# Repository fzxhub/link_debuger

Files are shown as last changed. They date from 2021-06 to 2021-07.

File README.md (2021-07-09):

# link_debuger_stm32
Includes STLINK JLINK DAPLINK, used for microcontroller debugging.
## 简介
本项目是一个link debuger，用于调试带有JTAG、SWD接口的微控制器。由于SWD接口的优势，以及本项目宗旨是做一个美观、小巧、功能全的调试器，因此查阅了许多开源电路、开源固件。最终做了该PCB。由上下两层PCB通过铜柱连接在一起。铜柱复用为上下板供电线路。
#### 优点
- 小巧、多功能
- 插针隐藏设计、方便携带
- 支持Jlink、STlink、DAPlink
- 支持RS485调试
- 支持ESP32等IC的自动下载（RTS、DTR信号预留）
- 使用Typec接口的对称性改成SWD、UART信号接口
- 采用底板顶板贴合设计、铜柱复用电源连接底板顶板
#### 实物展示
avatar

avatar

avatar

#### **底板3D图**
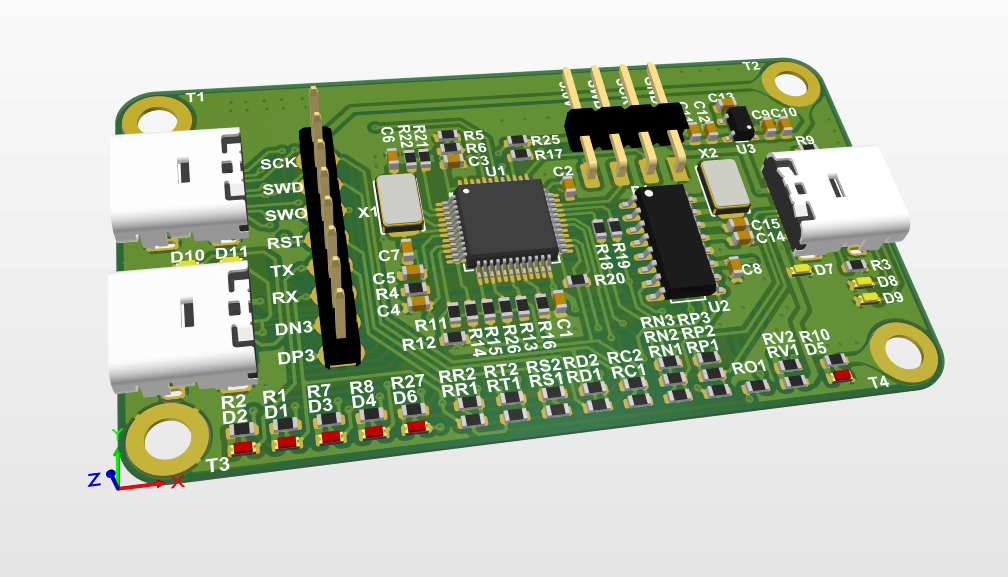
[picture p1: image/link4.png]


## 功能
1. debuger（jlink、stlink、daplink任意中的一种）
	- SWD接口下载和调试功能
	- link虚拟的串口功能（需要jlink、stlink、daplink固件支持）
	- link支持拖拽下载（需要jlink、stlink、daplink固件支持）
2. USB转UART（CP2102虚拟的串口）
3. USB转RS485（RS485由CP2102的UART电平转化，同一时刻只使用一种，EN接通使用RS485，不接使用UART）
4. USB HUB（可以再接入其他1个USB设备，TYPEC接口）
5. 信号线交叉硬件设计
## 功能说明
- link功能表示可是使用jlink、stlink、daplink任意一种固件，烧录入不同的link固件，该设备就是可以实现变身。
- USB转串口功能，因为三种固件都支持虚拟UART功能，因此都可以使用USB转UART（TTL），下载、调试、UART调试集一身。
- 除了固件虚拟的UART，再接入一个CP2102虚拟一个串口，该串口主要引出RTS、DTR信号，在目标板上合理设计可以自动下载ESP32、STM32串口下载。
- 还将CP2102虚拟的UART（TTL）进行电平转换后得到RS485接口，用于RS485调试
- 在输入USB接口之后绘制了一个USB HUB芯片，芯片是支持一拖四USB HUB，速率达到USB2.0。可通过电阻选择USB HUB是否使用。设计成可选择，主要防止USB HUB的不稳定造成link debugger的不稳定，如USB HUB不稳定或者不使用，可进行硬件上的切换。切换方式通过丝印在背面。
- 信号线交叉设计主要用于在电路设计时大意将例如UART的RX、TX接错时可切换debuger的电阻即可。切换方式通过丝印在背面。
- 本设计接口使用了typec USB接口定义了SWD接口、UART接口。在设计你的原型电路时，可以使用typec USB来设计SWD、UART接口后，通过typec USB线连接PC、link debuger、原型电路即可开始下载与调试。
- 该设备输出共四个typec USB：
  - typec USB1：SWD、UART接口
  - typec USB2：固件虚拟的UART接口 
  - typec USB3：CP2102虚拟的UART接口，带DTR、RTS信号
  - typec USB4：USB HUB接口
### **接口定义**
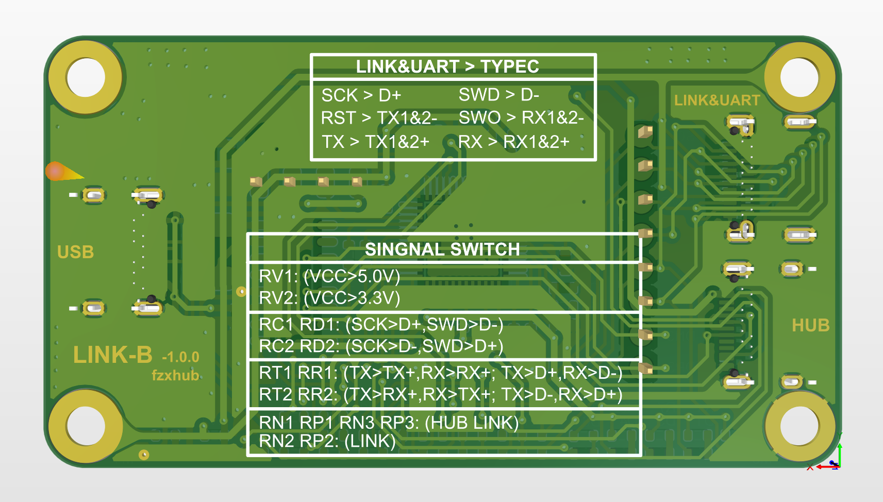
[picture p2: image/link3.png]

## 支持固件类型
1. jlink
2. stlink
3. daplink
## 支持接口与定义
说明：个人觉得嵌入式开发调试接口20PIN的牛角座端子太大，不适合在开发板或者项目电路板上使用，直接使用插针的方式在电路板使用，当迁移电路板后需要再次每根杜邦线连接，累~，在USB接口定义有可以直接使用的线和接口，因此我想使用USB线来做我们SWD、UART接口的使用。
我在之后的电路板、自绘开发上直接使用TYPEC接口母座来连接SWD、UART接口后，使用TYPEC线连接link_debuger和电路板即可开始使用。因此有了以下将USB接口信号改成SWD、UART接口的定义。
利用TYPEC正反插时的对称性。
1. typec USB类型的SWD&UART支持接口：
	- VCC、SCK、SWD、SWO、RST、TX、RX、GND
	- 接口对应
        | TYPEC母座信号定义 | 自定义SWD、UART信号 |
        | :---: | :---: |
        | VBUS | VCC |
        | D+(DP) | SCK（可与SWD交换） |
        | D-(DN) | SWD（可与SCK交换） |
        | TX1-&TX2- | RST |
        | RX1-&RX2-  | SWO |
        | TX1+&TX2+ | TX（可与RX交换） |
        | RX1+&RX2+ | RX（可与TX交换） |
        | GND | GND |

2. typec USB类型的UART
	- VCC、TX、RX、GND
	- 接口对应说明
        | TYPEC母座信号定义 | 自定义SWD、UART信号 |
        | :---: | :---: |
        | VBUS | VCC |
        | D-(DN) | TX（可与RX交换） |
        | D+(DP) | RX（可与TX交换） |
        | GND | GND |
3. typec USB类型的UART，带DTR、RTS信号
	- VCC、TX、RX、RTS、DTR、GND
	- 接口对应说明
        | TYPEC母座信号定义 | 自定义SWD、UART信号 |
        | :---: | :---: |
        | VBUS | VCC |
        | D-(DN) | RX（可与TX交换） |
        | D+(DP) | TX（可与RX交换） |
        | TX1+&TX2+ | DTR |
        | RX1+&RX2+ | RTS |
        | GND | GND |
4. typec USB类型的USB HUB2.0
	- 5.0V、D+、D-、GND
5. 2.54间距8PIN的SWD&UART接口
	- VCC、SCK、SWD、SWO、RST、TX、RX、GND
6. 2.54间距6PIN的UART接口
	- VCC、TX、RX、RTS、DTR、GND
7. 2.54间距2PIN的RS485接口（EN接通使用RS485，不接使用UART）
	- A、B
8. 2.54间距6PIN的供电
	- 3.3V、3.3V、5.0V、5.0V、GND、GND
9. 20PIN的JTAG接口（只支持SWD，默认不焊接，焊接20PIN贴片插针或者牛角座即可使用）
### **2.54间距接口图**
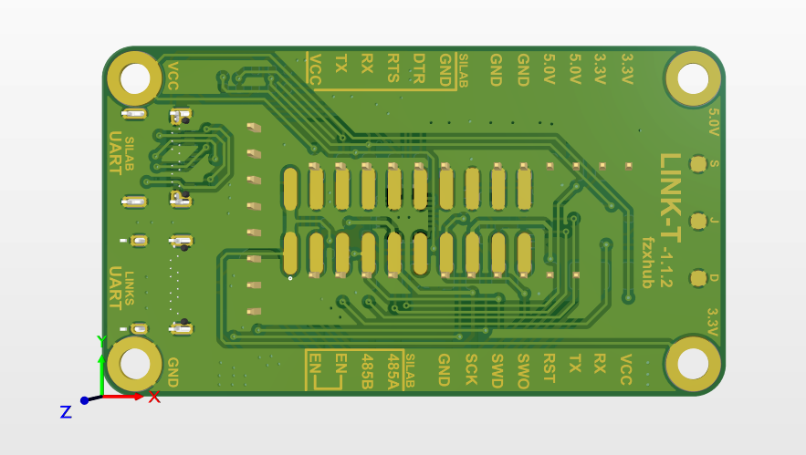
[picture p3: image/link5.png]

## 固件切换
1. 使用自己的STLINK与link_debuger的5.0V、SWD、SCK、GND连接。
2. 打开STM32 ST-LINK Utility
3. 连接设备
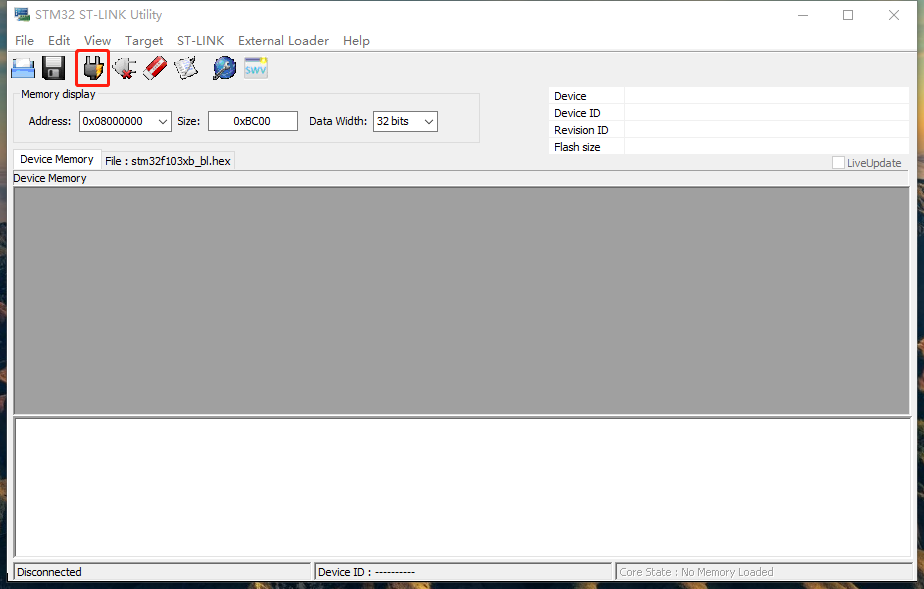
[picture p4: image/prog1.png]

4. 打开文件
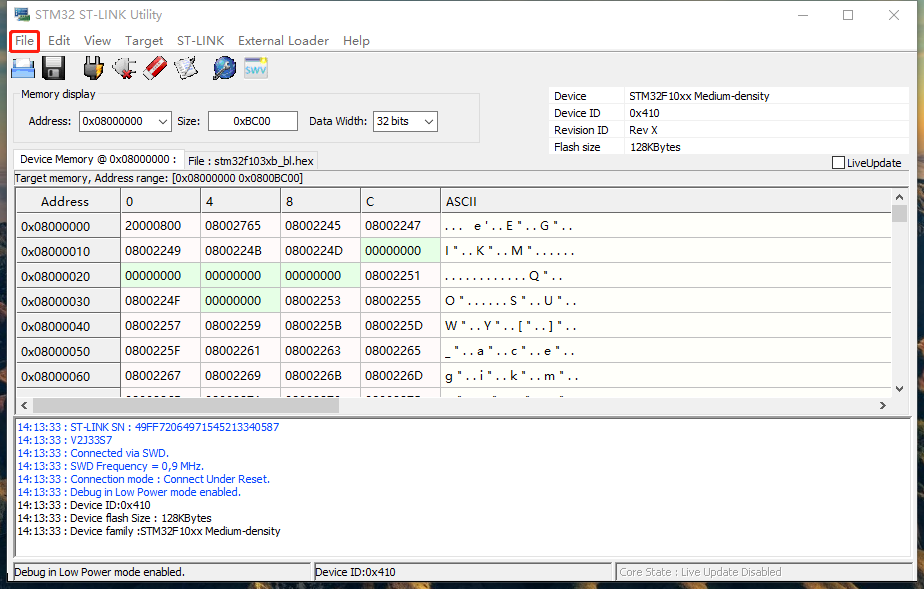
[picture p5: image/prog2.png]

5. 选择固件（DAP选择bootloader）
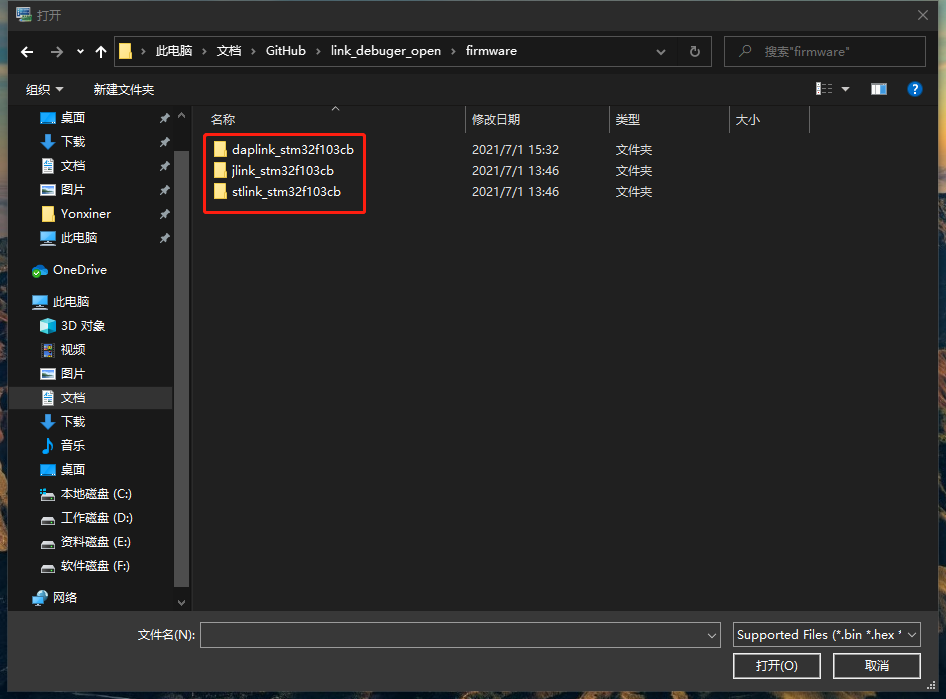
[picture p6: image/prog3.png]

6. 开始编程
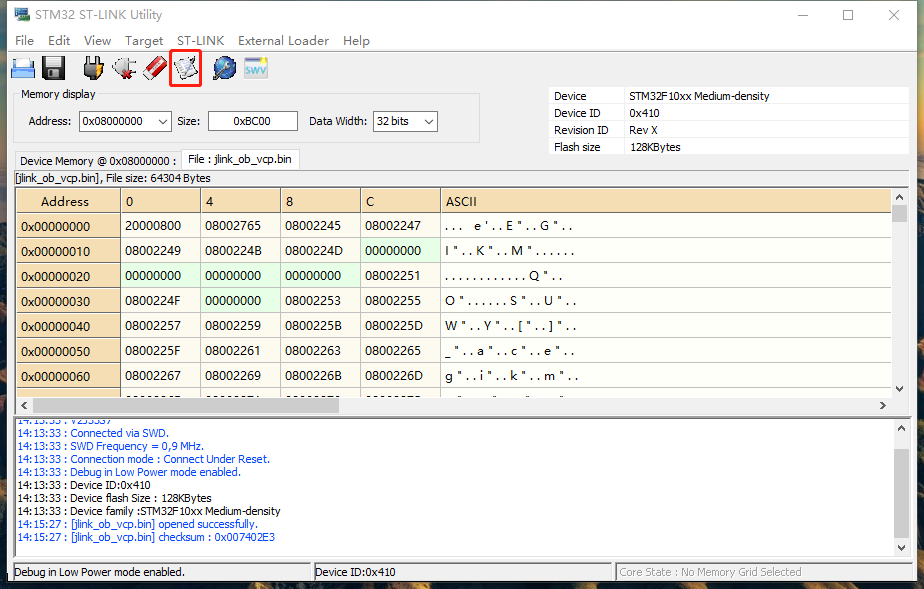
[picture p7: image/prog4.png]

7. 点击start、等待进度条完成后即可使用
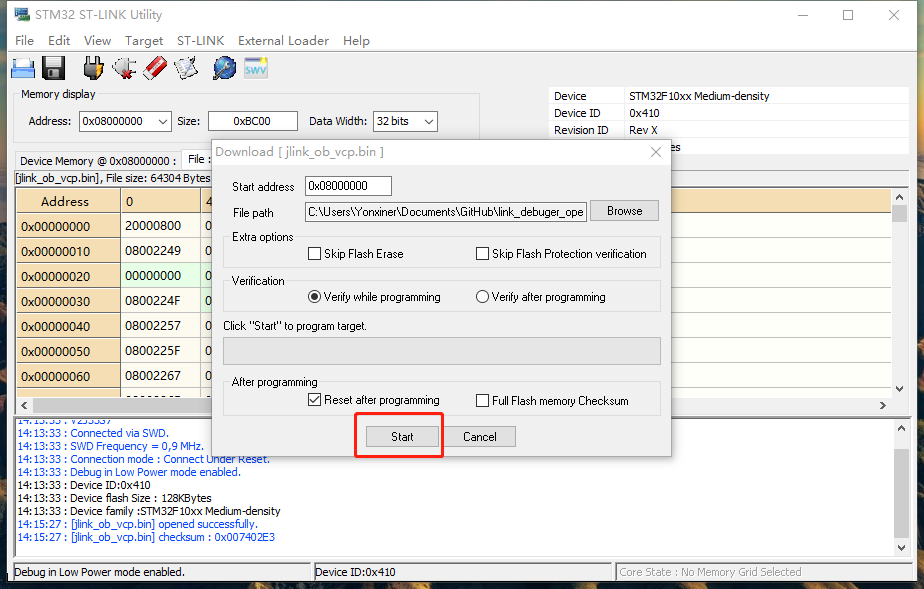
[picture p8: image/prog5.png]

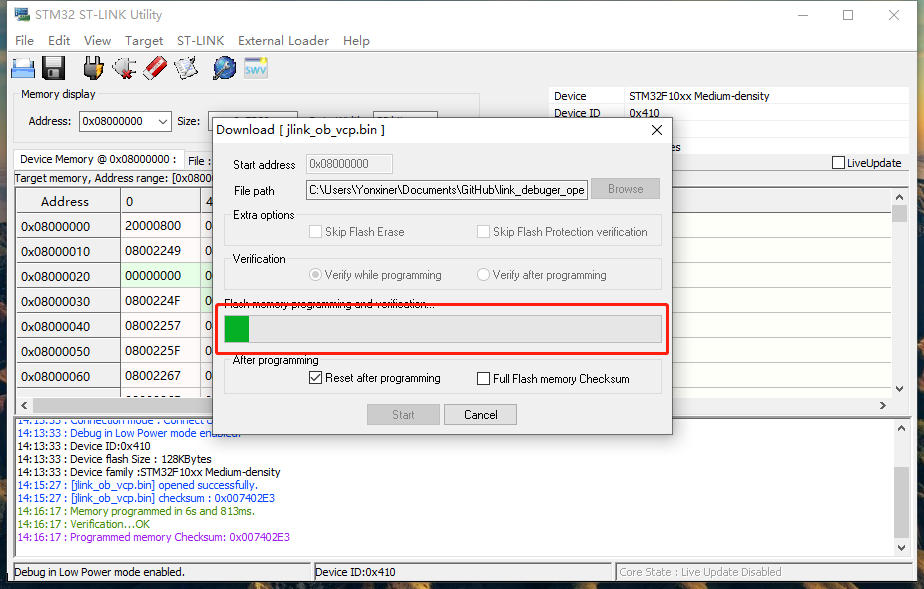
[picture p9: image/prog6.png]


作者：fzxhub

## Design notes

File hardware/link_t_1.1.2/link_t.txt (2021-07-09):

Board Information Report
Filename     : C:\Users\Yonxiner\Documents\GitHub\link_debuger_stm32\hardware\link_t_1.1.1\link_t.PcbDoc
Date         : 2021/7/5
Time         : 19:08:10
Time Elapsed : 00:00:00

Routing Information
    Routing completion, 100.00%
    Connections, 127
    Connections routed, 127
    Connections remaining, 0
count : 4

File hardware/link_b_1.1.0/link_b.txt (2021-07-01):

Board Information Report
Filename     : C:\Users\Yonxiner\Desktop\hardware\link_b.PcbDoc
Date         : 2021/6/26
Time         : 11:01:15
Time Elapsed : 00:00:00

Routing Information
    Routing completion, 100.00%
    Connections, 238
    Connections routed, 238
    Connections remaining, 0
count : 4

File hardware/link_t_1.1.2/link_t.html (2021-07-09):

Altium customize

# Board Information Report

Date: | | 2021/7/5
Time: | | 19:08:10
Elapsed Time: | | 00:00:00
Filename: | | C:\Users\Yonxiner\Documents\GitHub\link_debuger_stm32\hardware\link_t_1.1.1\link_t.PcbDoc

## Contents

Contents

Routing

Routing Information

## Routing

Routing Information
Routing completion | 100.00%
Connections | 127
Connections routed | 127
Connections remaining | 0

Back to top

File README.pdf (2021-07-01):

# link_debuger_stm32

简介

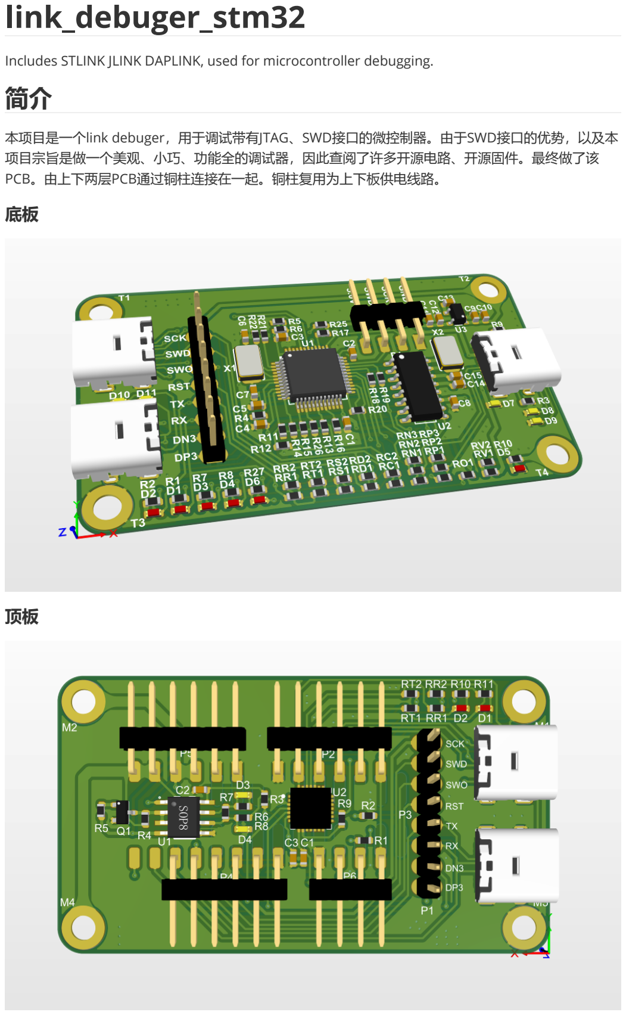
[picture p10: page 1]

Includes STLINK JLINK DAPLINK, used for microcontroller debugging.

本项目是一个link debuger，用于调试带有JTAG、SWD接口的微控制器。由于SWD接口的优势，以及本 项目宗旨是做一个美观、小巧、功能全的调试器，因此查阅了许多开源电路、开源固件。最终做了该 PCB。由上下两层PCB通过铜柱连接在一起。铜柱复用为上下板供电线路。
底板

顶板

功能

# 功能说明

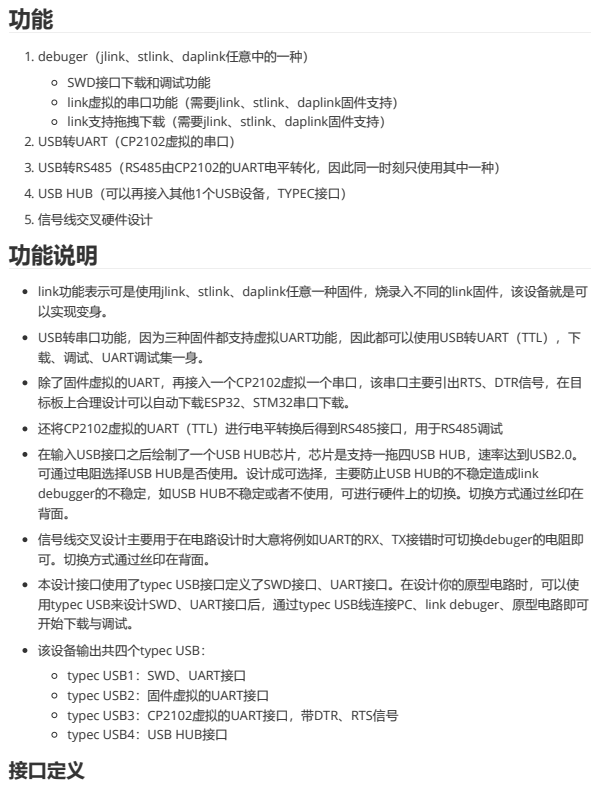
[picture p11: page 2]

1. debuger（jlink、stlink、daplink任意中的一种）
SWD接口下载和调试功能
link虚拟的串口功能（需要jlink、stlink、daplink固件支持）
link支持拖拽下载（需要jlink、stlink、daplink固件支持）
2. USB转UART（CP2102虚拟的串口）
3. USB转RS485（RS485由CP2102的UART电平转化，因此同一时刻只使用其中一种）
4. USB HUB（可以再接入其他1个USB设备，TYPEC接口）
5. 信号线交叉硬件设计

link功能表示可是使用jlink、stlink、daplink任意一种固件，烧录入不同的link固件，该设备就是可
以实现变身。
USB转串口功能，因为三种固件都支持虚拟UART功能，因此都可以使用USB转UART（TTL），下
载、调试、UART调试集一身。
除了固件虚拟的UART，再接入一个CP2102虚拟一个串口，该串口主要引出RTS、DTR信号，在目
标板上合理设计可以自动下载ESP32、STM32串口下载。
还将CP2102虚拟的UART（TTL）进行电平转换后得到RS485接口，用于RS485调试
在输入USB接口之后绘制了一个USB HUB芯片，芯片是支持一拖四USB HUB，速率达到USB2.0。
可通过电阻选择USB HUB是否使用。设计成可选择，主要防止USB HUB的不稳定造成link
debugger的不稳定，如USB HUB不稳定或者不使用，可进行硬件上的切换。切换方式通过丝印在
信号线交叉设计主要用于在电路设计时大意将例如UART的RX、TX接错时可切换debuger的电阻即
可。切换方式通过丝印在背面。
本设计接口使用了typec USB接口定义了SWD接口、UART接口。在设计你的原型电路时，可以使
用typec USB来设计SWD、UART接口后，通过typec USB线连接PC、link debuger、原型电路即可
开始下载与调试。
该设备输出共四个typec USB：
typec USB1：SWD、UART接口
typec USB2：固件虚拟的UART接口
typec USB3：CP2102虚拟的UART接口，带DTR、RTS信号
typec USB4：USB HUB接口
接口定义

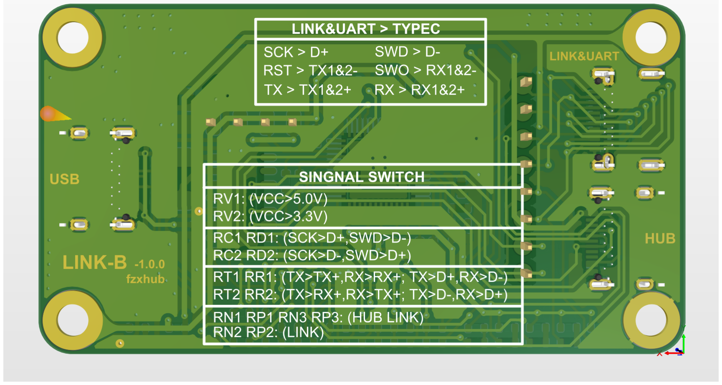
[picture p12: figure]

# 支持固件类型

1. jlink
2. stlink
3. daplink

# 支持接口

1. typec USB类型的SWD&UART接口： VCC、SCK、SWD、SWO、RST、TX、RX、GND
2. typec USB类型的UART
VCC、TX、RX、GND
3. typec USB类型的UART，带DTR、RTS信号 VCC、TX、RX、RTS、DTR、GND
4. typec USB类型的USB HUB2.0
5.0V、D+、D-、GND
5. 8PIN的SWD&UART接口
VCC、SCK、SWD、SWO、RST、TX、RX、GND
6. 6PIN的UART接口
VCC、TX、RX、RTS、DTR、GND
7. 4PIN的RS485接口
VCC、A、B、GND
8. 6PIN的供电
3.3V、3.3V、5.0V、5.0V、GND、GND
9. 20PIN的JTAG接口（只支持SWD，默认不焊接，焊接20PIN贴片插针或者牛角座即可使用）

## 部分接口图

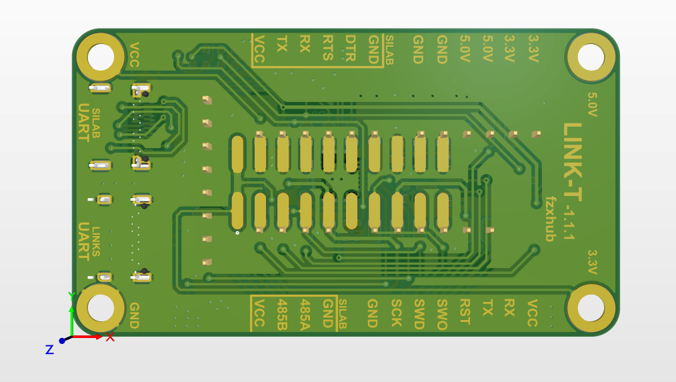
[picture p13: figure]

# 固件切换

1. 切换jlink
2. 切换stlink
3. 切换daplink
作者：fzxhub

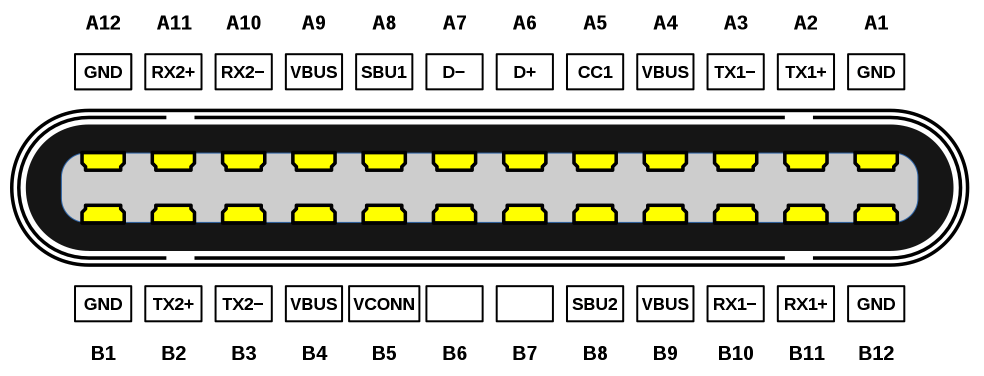
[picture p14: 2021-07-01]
image/typec1.png

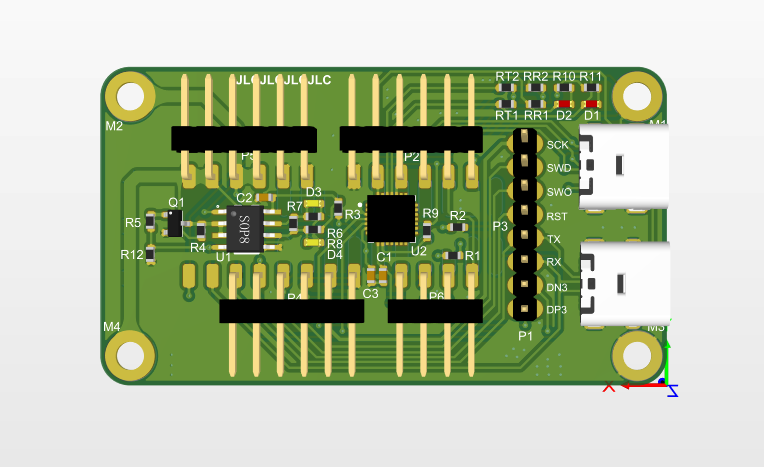
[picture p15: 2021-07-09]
image/link6.png

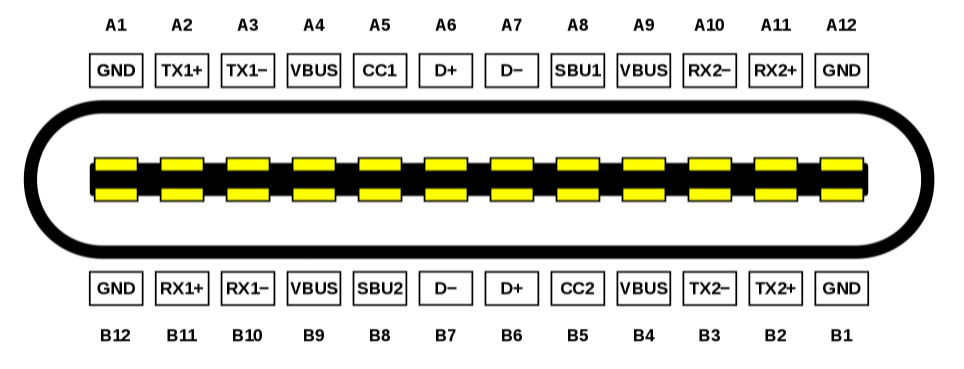
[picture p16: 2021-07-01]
image/typec2.png

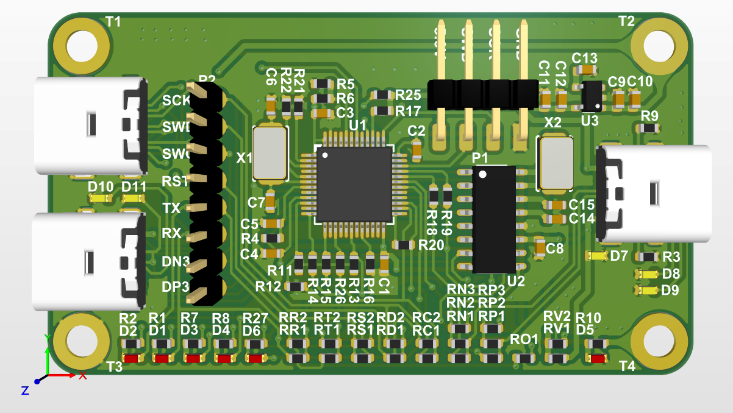
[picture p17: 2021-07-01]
image/link2.png

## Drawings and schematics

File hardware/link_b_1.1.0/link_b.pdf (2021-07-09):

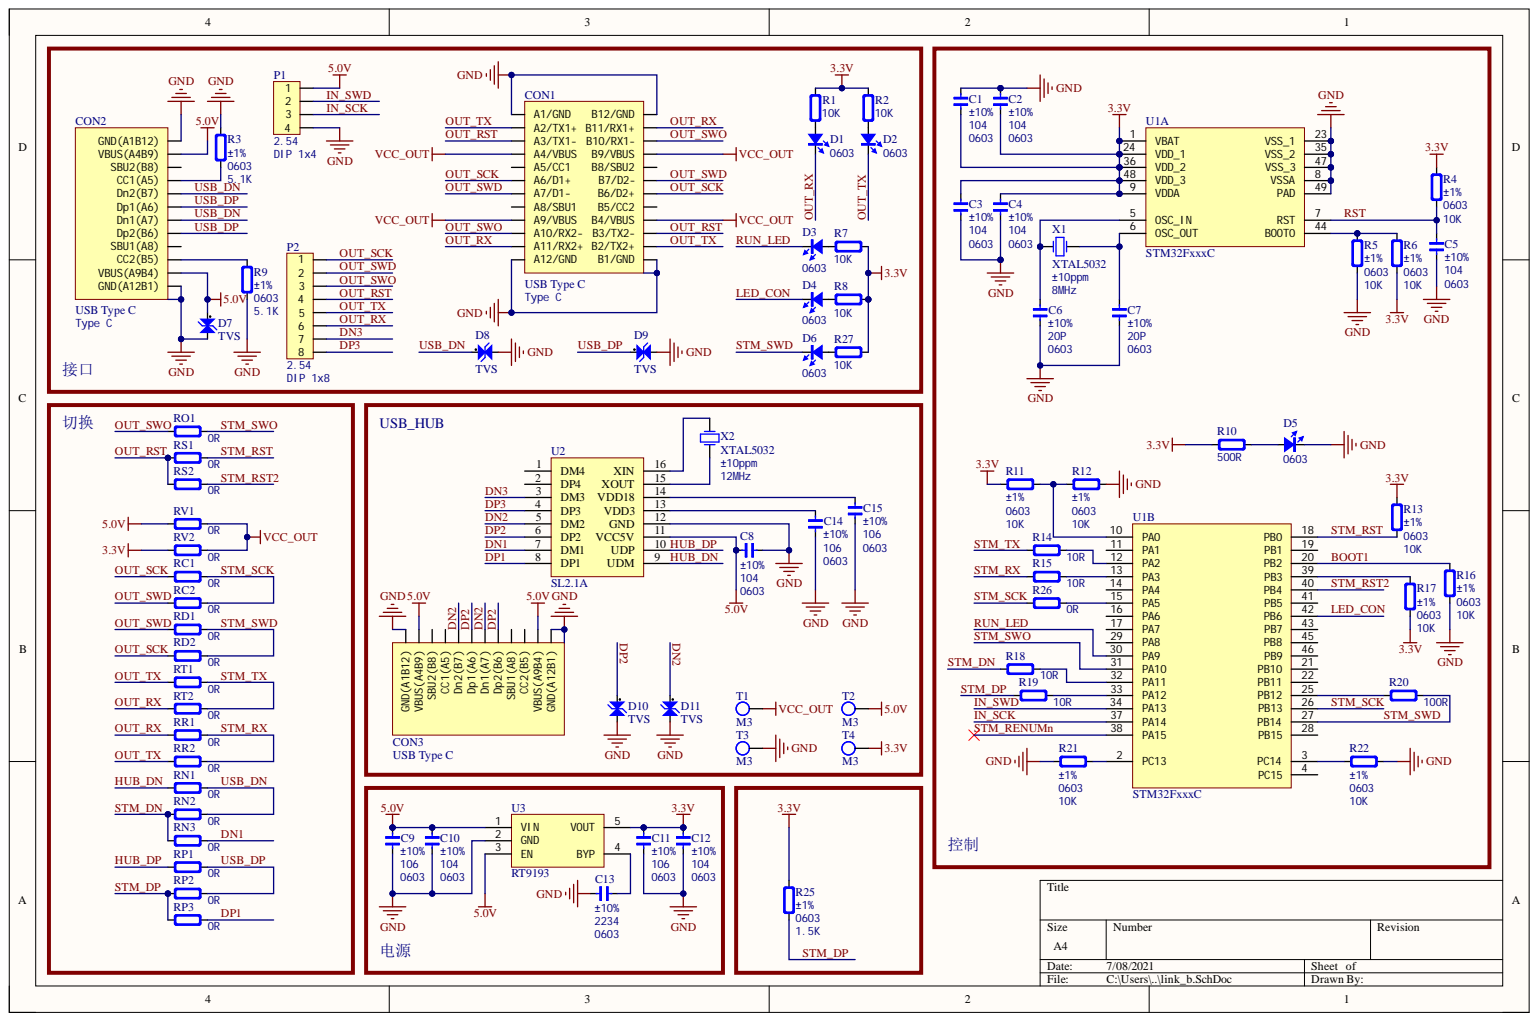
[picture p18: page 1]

Comment | Description | Designator | Footprint | LibRef | Quantity
C0603 | Capacitor | C1, C2, C3, C4, C5, C6, C7, C8, C9, C10, C11, C12, C13, C14, C15 | CAP_0603 | Cap_0603 | 15
USB Type C | USB | CON1 | USB_TypeC_SMD_24 P | USB_TypeC | 1
USB Type C | USB | CON2, CON3 | USB_TypeC_SMD_16 P | USB_TypeC_16P | 2
D0603 | LED | D1, D2, D3, D4, D5, D6 | LED_0603_RED | LED_0603 | 6
TVS | 静电保护二极 管,VRWM=5V.IPP=9. 4A | D7, D8, D9, D10, D11 | LED_0603_YELLOW | ESD LESD5D5.0CT1G | 5
HDR1x4 | Header Top | P1 | HDR1x4_TOP | HDR1x4_2.54TOP | 1
HDR1x8 | Header Top | P2 | HDR1x8_TOP | HDR1x8_2.54TOP | 1
R0603 | Resistor

R1, R2, R3, R4, R5,
R6, R7, R8, R9, R10,
R11, R12, R13, R14,
R15, R16, R17, R18,
R19, R20, R21, R22,
R25, R26, R27, RC1,
RC2, RD1, RD2, RN1,
RN2, RN3, RO1, RP1,
RP2, RP3, RR1, RR2,
RS1, RS2, RT1, RT2,

# RV1, RV2

RES_0603 | Res_0603 | 44
M3 | M3 Nut | T1, T2, T3, T4 | M3 | M3 | 4
STM32FxxxC | MCU ST | U1 | LQFP_QNF_48 | STM32FxxxC | 1
SL2.1A | USB HUB | U2 | SOP16 | SL2.1A | 1
RT9193 | Power | U3 | SOT23-5 | RT9193 | 1
XTAL5032 | Crystal Oscillator | X1, X2 | XT_5032_2 | XTAL_5032_2P | 2

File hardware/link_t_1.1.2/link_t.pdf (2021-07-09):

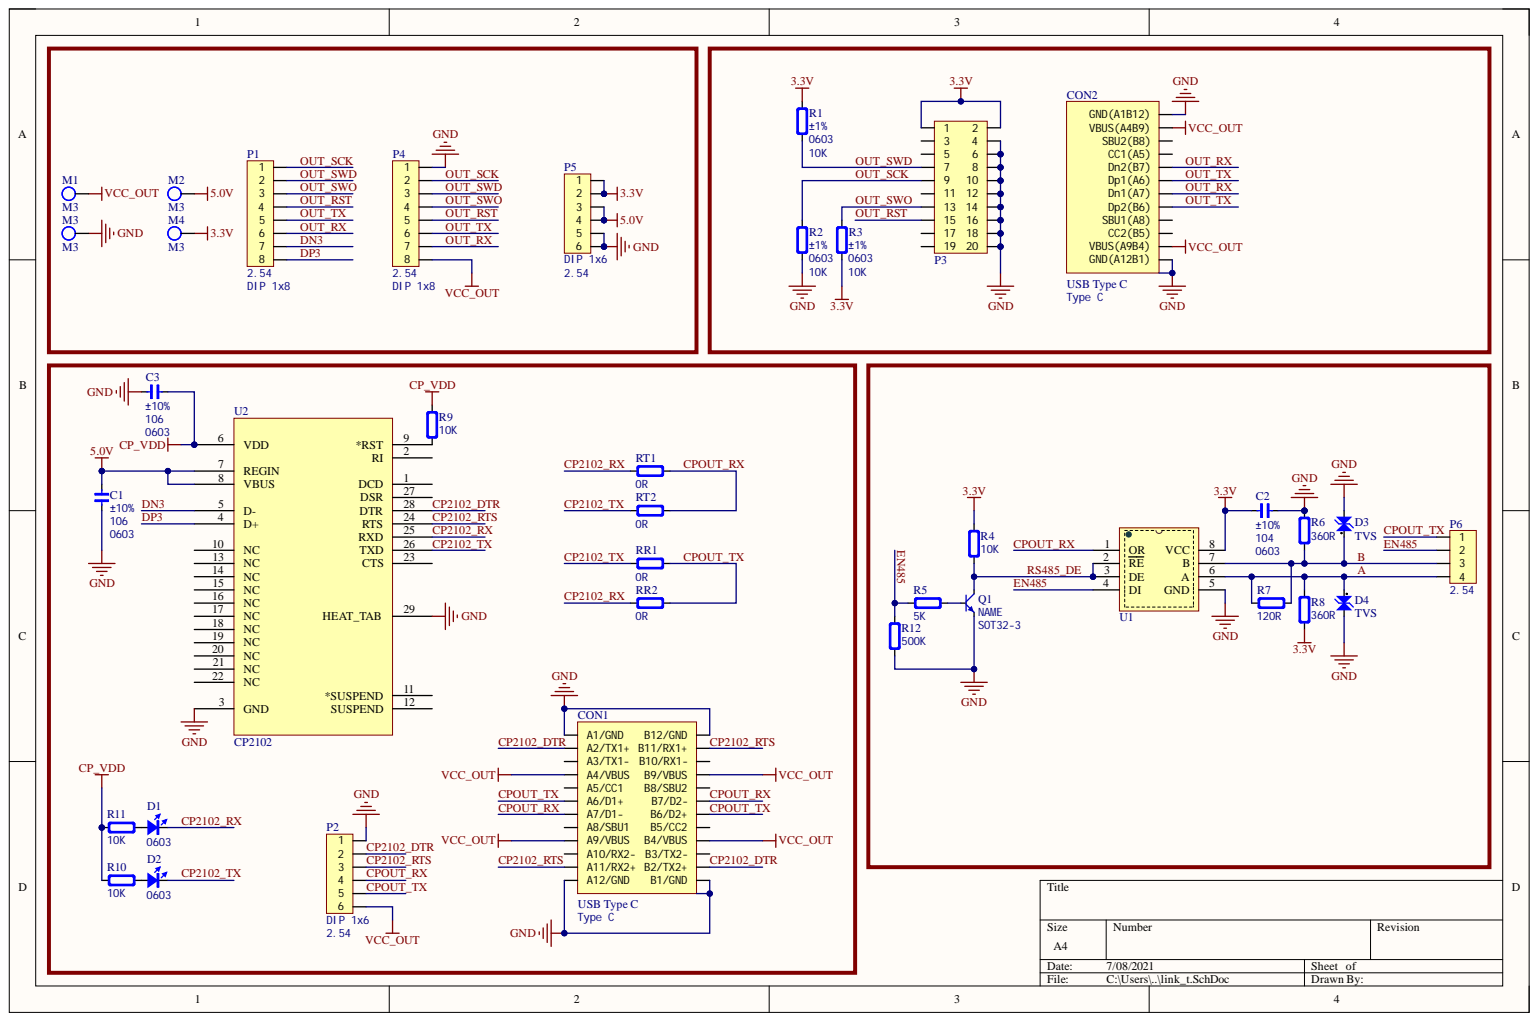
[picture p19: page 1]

OUT_RX | OUT_TX
DN3 | OUT_RX

Comment | Description | Designator | Footprint | LibRef | Quantity
C0603 | Capacitor | C1, C2, C3 | CAP_0603 | Cap_0603 | 3
USB Type C | USB | CON1 | USB_TypeC_SMD_24 P | USB_TypeC | 1
USB Type C | USB | CON2 | USB_TypeC_SMD_16 P | USB_TypeC_16P | 1
D0603 | LED | D1, D2 | LED_0603_RED | LED_0603 | 2
TVS | 静电保护二极 管,VRWM=5V.IPP=9. 4A | D3, D4 | LED_0603_YELLOW | ESD LESD5D5.0CT1G | 2
M3 | M3 Nut | M1, M2, M3, M4 | M3 | M3 | 4
HDR1x8 | Header Top | P1 | HDR1x8_TOP | HDR1x8_2.54TOP | 1
HDR1x6 | Header Top | P2, P5 | HDR1x6_TOP | HDR1x6_2.54TOP | 2
HDR2x10 | Header | P3 | JN_STM_20PIN | HDR2x10_2.54 | 1
HDR1x8 | Header Top | P4 | HDR1X8_H | HDR1x8_2.54TOP | 1
HDR1x4 | Header Top | P6 | HDR1x4_TOP | HDR1x4_2.54TOP | 1
NAME | Transistor | Q1 | SOT23-3 | BJT_NPN | 1
R0603 | Resistor | R1, R2, R3, R4, R5, R6, R7, R8, R9, R10, R11, R12, RR1, RR2, RT1, RT2 | RES_0603 | Res_0603 | 16
SP3485 | 半双工收发器 | U1 | SOP8 | SP3485 | 1
CP2102 | USB转TTL | U2 | QFN-28 | CP2102 | 1

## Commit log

2021-06-19 即将上传PCB和固件
2021-06-19 修改简介
2021-07-01 增加底板硬件、增加固件
    [link_b.PrjPcb, link_b.SchDoc]
2021-07-01 更新DAP固件
2021-07-09 测试完成，可以使用了
    [link_t.PcbDoc, link_t.PrjPcb, link_t.SchDoc]
